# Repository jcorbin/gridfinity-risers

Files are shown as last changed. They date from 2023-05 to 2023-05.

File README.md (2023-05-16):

# Gridfinity Riser Modules

These are some riser modules useful for creating "cable basements" or otherwise
managing cable runs inside a gridfinity application.

Published STL models are published on [thangs](https://than.gs/m/853821)

Status:
- [x] working tunnel block for routing cables underneath a raised floor
- [x] tunnel towers can provide a sort of vertical conduit and/or support other
  modules; for example a AA battery charger stacked on top of a AA battery
  dispenser chute
- [x] tunnel sizes are reasonably flexible, clamping to available block space,
  and degrading to non-square rectangular tunnels when necessary
- [ ] consider switching the default tunnel size to 4u
- [ ] a baseplate variant of the tunnel block that is designed to sit well on a non-grid surface
  - maybe support edge pins to lock together multiple modules
  - maybe support cutting out voids for small devices embedded into the cable floor

## Tunnel Block

The primary module is a relatively solid/heavy block with tunnels cut along all 3 X/Y/Z axes for running cables.
The default tunnel size is 3u (21mm), which embeds well in a 4u-tall block.

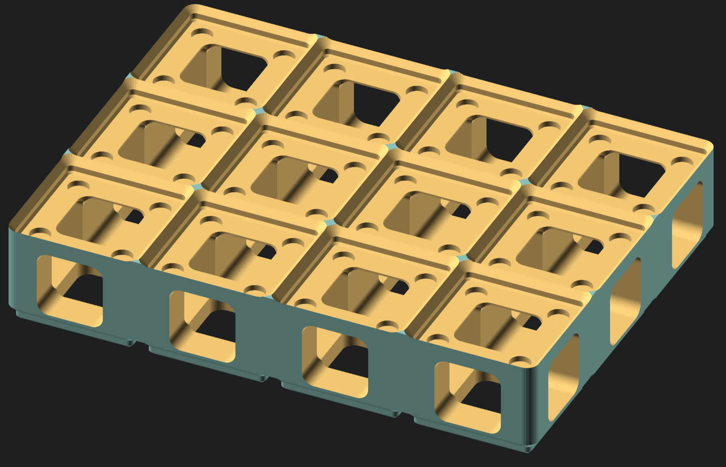
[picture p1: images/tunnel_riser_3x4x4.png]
Tunnel Block 3x4x4


## Tunnel Tower

When a tunnel block is scaled large enough in the Z axis, there will be
multiple layers of X/Y oriented tunnels, forming a tower.

With necessary margin, an `N` unit tall tunnel willl repeat every `N+1` units;
so the default 3u tunnel should repeat every 4u.

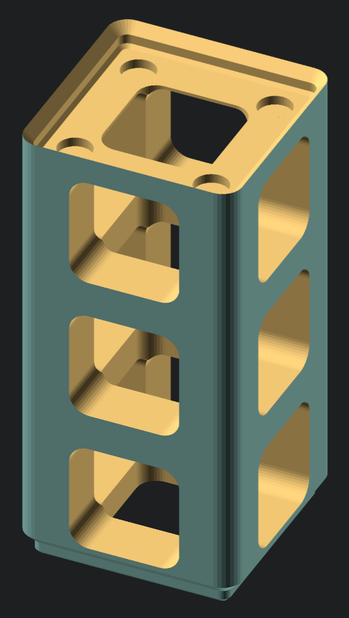
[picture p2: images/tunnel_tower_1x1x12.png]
Tunnel Tower 1x1x12


## Tunnel Baseplate

This is a variant of the tunnel block with a flat bottom meant to be used as a baseplate:
- features rabbit clips and sockets to allow multiple basepaltes to be locked together
- features pockets for rubber feet, default setup for 6x2mm feet (0.5mm deep pockets)

These are designed for a desktop grid module that you don't want to accidentally slide around.

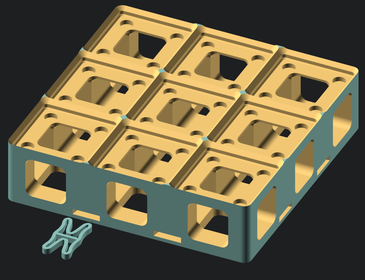
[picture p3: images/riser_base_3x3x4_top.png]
Tunnel Baseplate (top view)

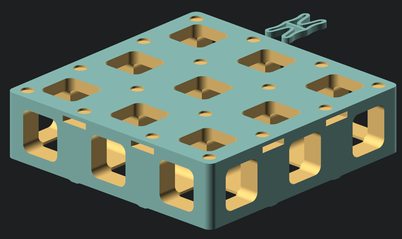
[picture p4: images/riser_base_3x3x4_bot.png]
Tunnel Baseplate (bottom view)


## Hexagonal Walled Cups

Inspired by a question in the Gridfinity discord, this is a recreation of a
gridfinity cup with most of the wall material cut out by a hexagon grid.
This model was created similarly to the tunnerl riser above,
using [vector76] gridfinity mmodules and [bosl2] to manage the hexagaon window cutouts.

A potential use here would be a stackable bin, whose contents would still be
visble thru the side when stacked:
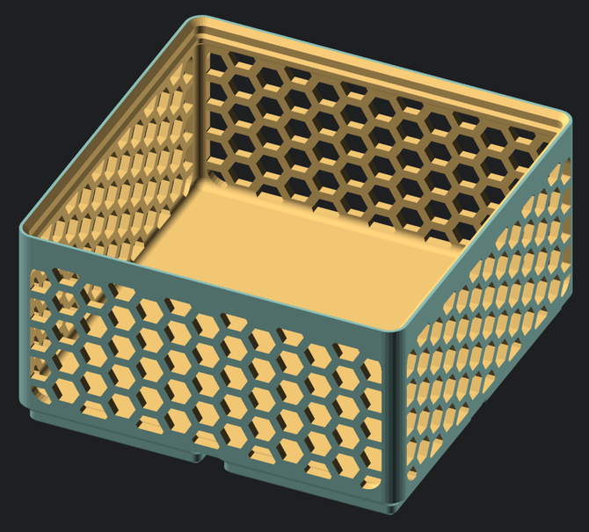
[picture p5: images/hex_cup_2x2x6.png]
Hex Cup 2x2x6


Or a non-stacking pen cup:
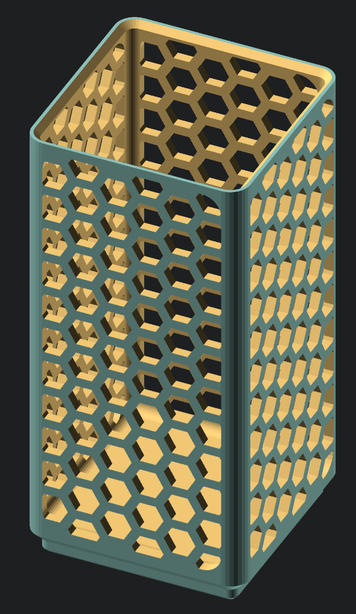
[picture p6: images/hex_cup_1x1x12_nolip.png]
Hex Cup 1x1x12 (no lip)


A similar cup can be seen in a picture uploaded by [ashleyi100 on thangs][ashleyi100]
which looks similar to this [non gridfinity box][hcomb_box] on printables.

## Raised Base

The initial design was a "legged table" based on [vector76] `frame_plain()` with extra height.

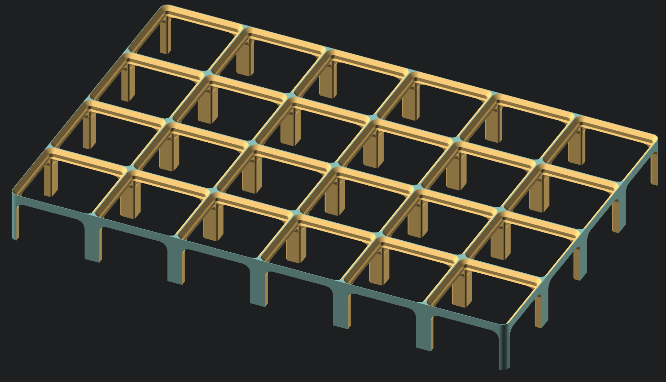
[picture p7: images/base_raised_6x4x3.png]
Raised Base "leg table" 6x4x3


This version didn't feel great in practice,
as the legs would chatter/skip over the external surface,
allowing cables to jump/dislocate too easily.

[ashleyi100]: https://thangs.com/designer/ashleyi100
[bosl2]: https://github.com/revarbat/BOSL2
[hcomb_box]: https://www.printables.com/model/250845-honeycomb-pattern-box-with-label
[vector76]: https://github.com/vector76/gridfinity_openscad

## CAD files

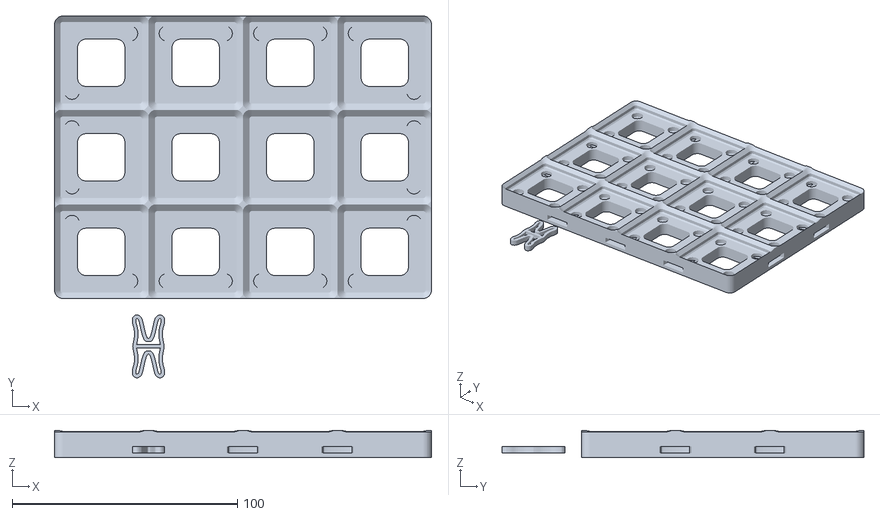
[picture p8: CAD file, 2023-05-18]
base_models/grid_base_4x3_with_clip.stl
167.5 x 160.8 x 12.0

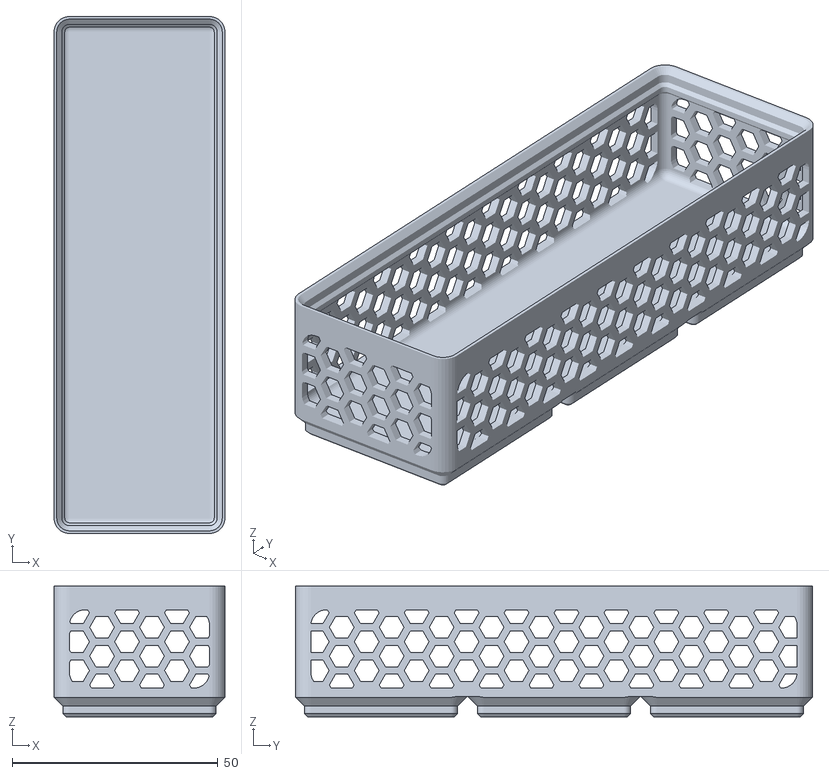
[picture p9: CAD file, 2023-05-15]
hex_cup_models/hex_cup_1x3x4.stl
41.5 x 125.5 x 31.8

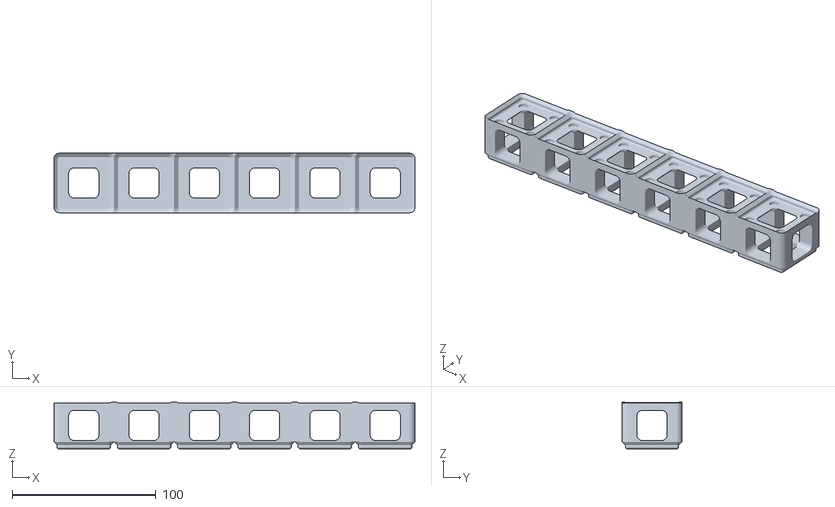
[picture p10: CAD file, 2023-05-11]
riser_models/tunnel_riser_6x1x4.stl
251.5 x 41.5 x 32.4

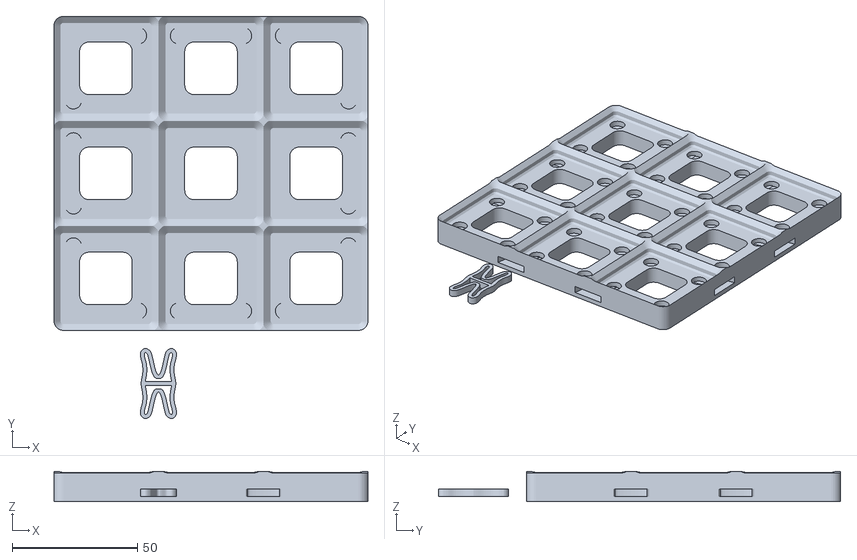
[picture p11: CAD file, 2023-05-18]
base_models/grid_base_3x3_with_clip.stl
125.5 x 160.8 x 12.0

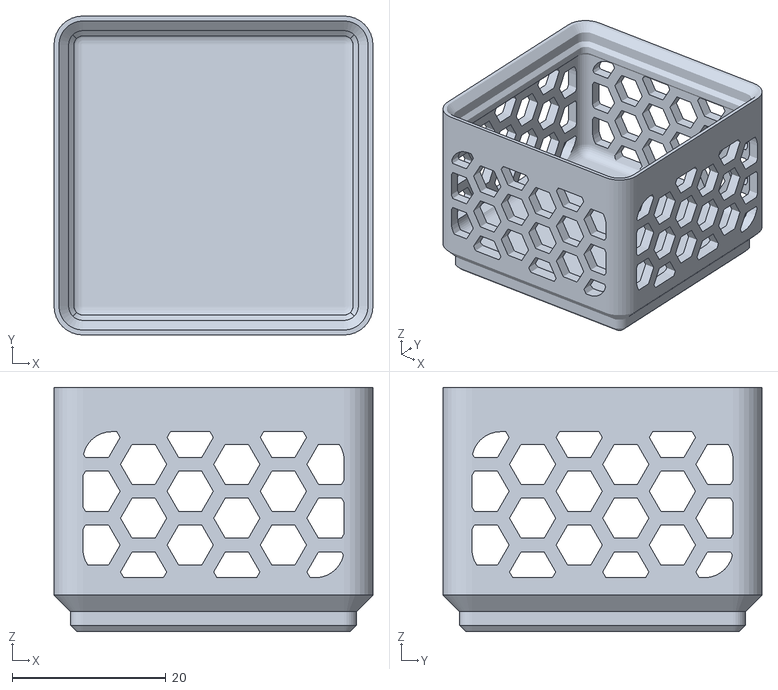
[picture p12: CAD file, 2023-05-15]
hex_cup_models/hex_cup_1x1x4_nolip.stl
41.5 x 41.5 x 31.8

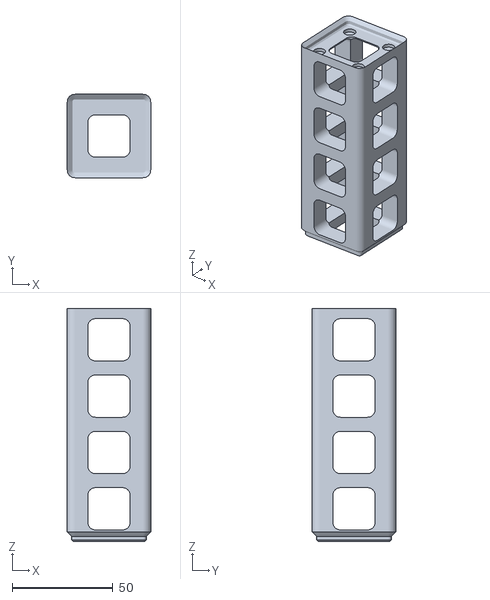
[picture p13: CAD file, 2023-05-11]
riser_models/tunnel_tower_1x1x16.stl
41.5 x 41.5 x 115.8

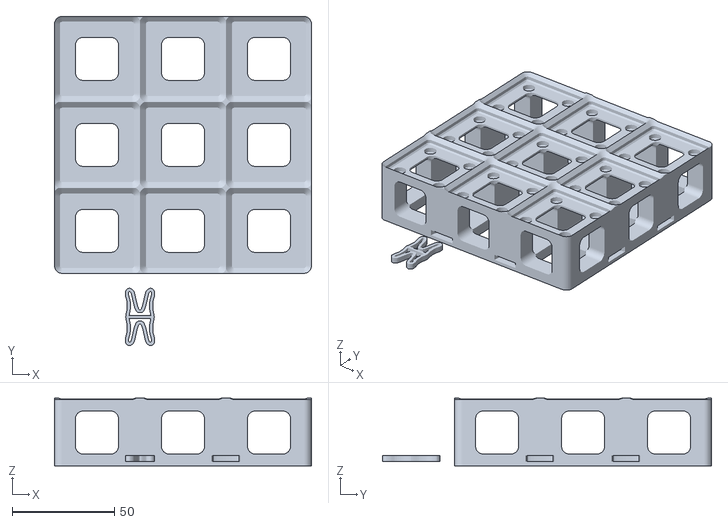
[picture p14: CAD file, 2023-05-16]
base_models/tunnel_base_3x3x4_with_clip.stl
125.5 x 160.8 x 33.0

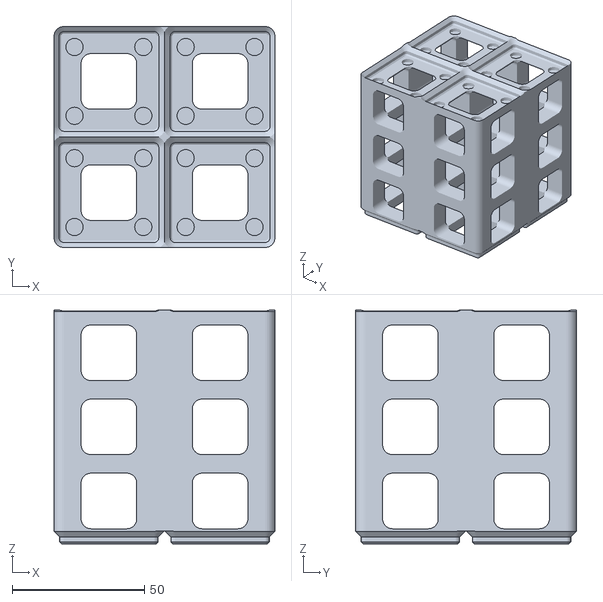
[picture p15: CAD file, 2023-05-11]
riser_models/tunnel_tower_2x2x12.stl
83.5 x 83.5 x 88.4

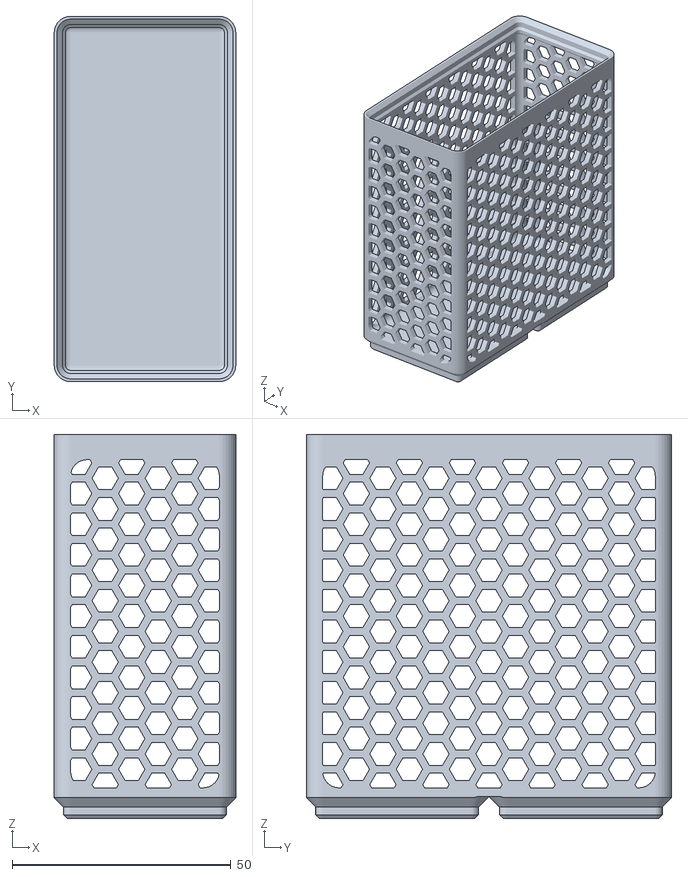
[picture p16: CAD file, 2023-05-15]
hex_cup_models/hex_cup_1x2x12.stl
41.5 x 83.5 x 87.8

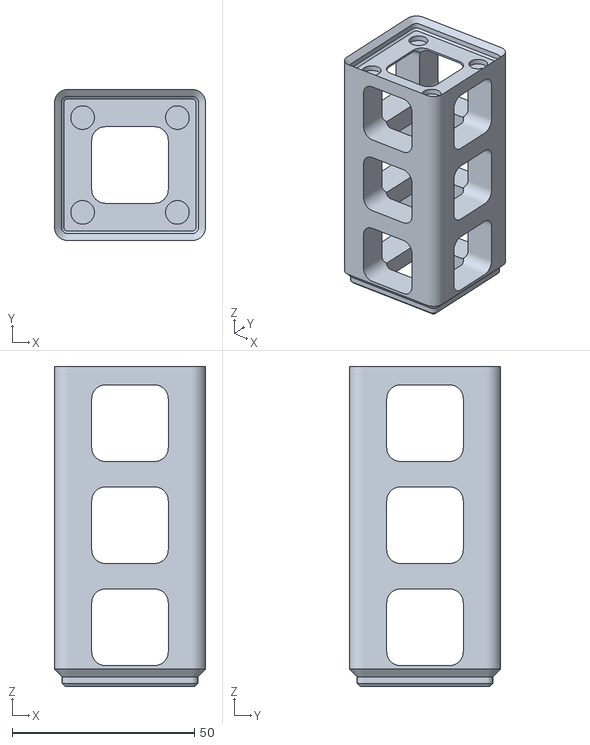
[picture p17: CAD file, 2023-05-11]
riser_models/tunnel_tower_1x1x12.stl
41.5 x 41.5 x 87.8

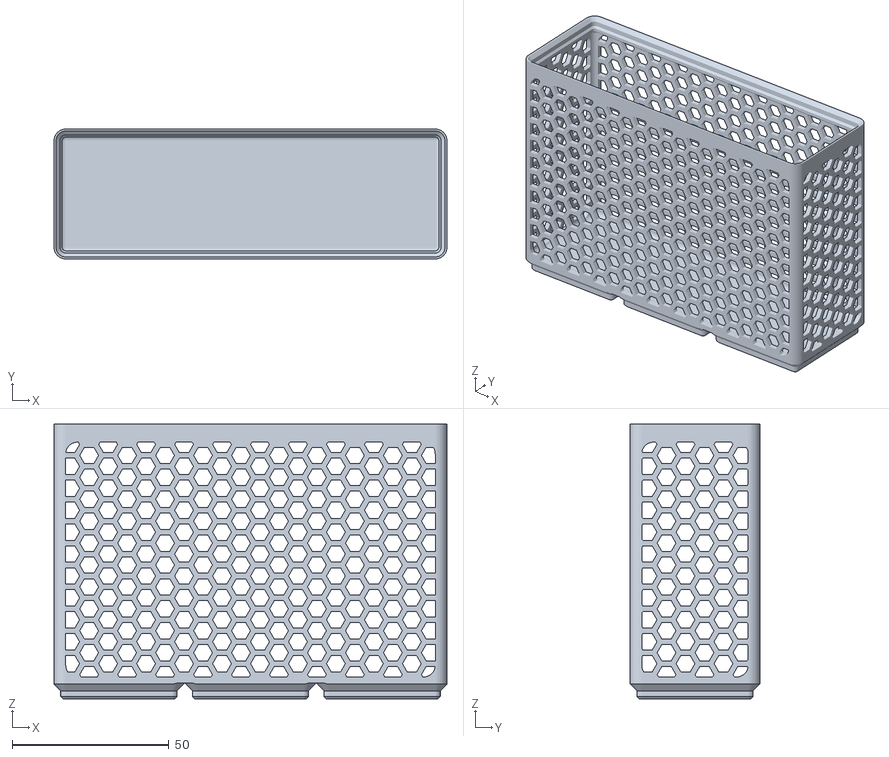
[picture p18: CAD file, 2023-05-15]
hex_cup_models/hex_cup_3x1x12.stl
125.5 x 41.5 x 87.8

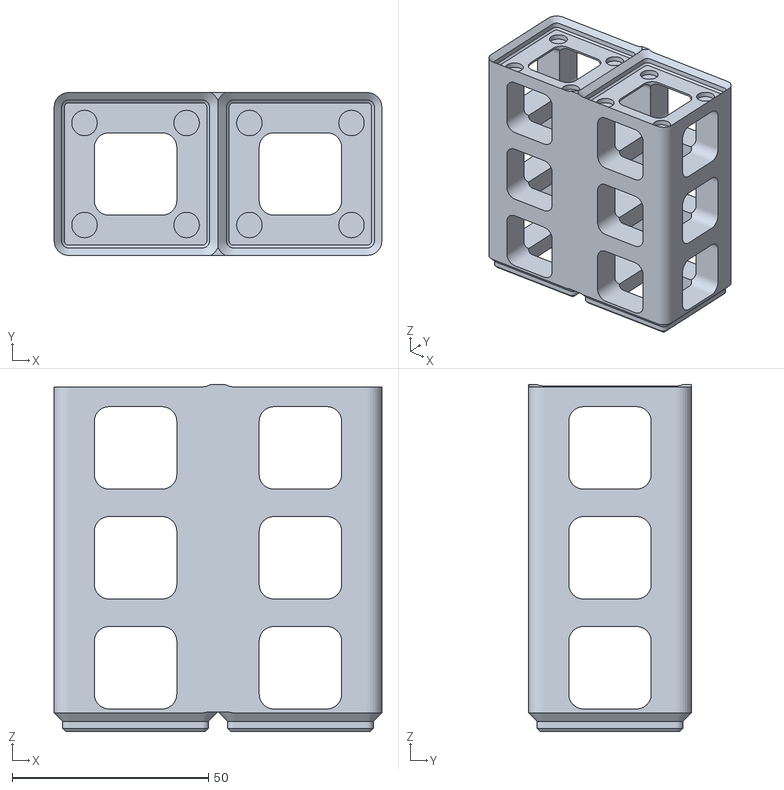
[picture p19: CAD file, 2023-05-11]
riser_models/tunnel_tower_2x1x12.stl
83.5 x 41.5 x 88.4

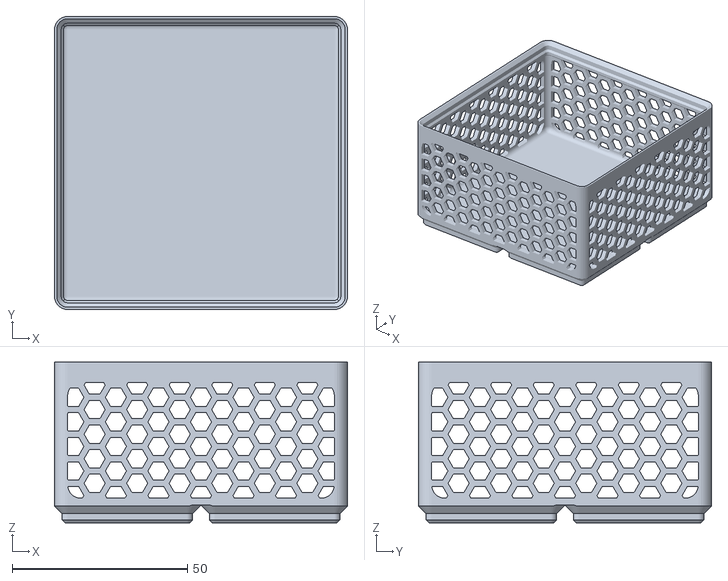
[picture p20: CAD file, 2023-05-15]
hex_cup_models/hex_cup_2x2x6.stl
83.5 x 83.5 x 45.8

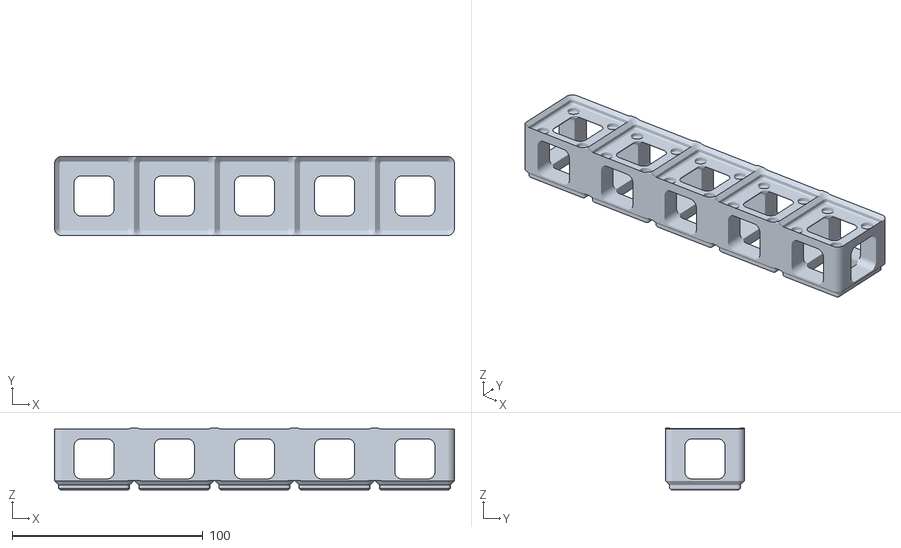
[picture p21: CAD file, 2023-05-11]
riser_models/tunnel_riser_5x1x4.stl
209.5 x 41.5 x 32.4

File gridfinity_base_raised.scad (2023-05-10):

include <vector76/gridfinity_modules.scad>
include <BOSL2/std.scad>

xsize = 6;
ysize = 4;
zsize = 3;

base_raised(xsize, ysize, raise=zsize);

module base_raised(num_x, num_y, raise=1) {
  difference() {
    corner_radius = 3.75;
    corner_position = gridfinity_pitch/2-corner_radius;

    height = gridfinity_zpitch * raise;
    door_width = 42 - 2*corner_radius;
    frame_height = 4.4;

    hull()
      cornercopy(corner_position, num_x, num_y)
      translate([0, 0, -height])
      cylinder(r=corner_radius, h=frame_height + height, $fn=44);

    translate([0, 0, -0.01])
      render()
      gridcopy(num_x, num_y)
      pad_oversize(margins=1);

    translate([0, 0, -(height+0.5)])
      cutout(num_x, num_y, h=height+1, margins=1);


    for(i=[0:num_x-1])
      translate([i * gridfinity_pitch, (num_y/2 - 0.5) * gridfinity_pitch, 0])
        cuboid([door_width, (num_y+0.5)*gridfinity_pitch, height+1], rounding=corner_radius, edges=TOP, anchor=TOP);

    for(i=[0:num_y-1])
      translate([(num_x/2 - 0.5) * gridfinity_pitch, i * gridfinity_pitch, 0])
        cuboid([(num_x+0.5)*gridfinity_pitch, door_width, height+1], rounding=corner_radius, edges=TOP, anchor=TOP);
  }
}

module cutout(num_x=1, num_y=1, h=1, margins=0) {
  pad_corner_position = gridfinity_pitch/2 - 4; // must be 17 to be compatible
  bevel1_top = 0.8;     // z of top of bottom-most bevel (bottom of bevel is at z=0)
  bevel2_bottom = 2.6;  // z of bottom of second bevel
  bevel2_top = 5;       // z of top of second bevel
  bonus_ht = 0.2;       // extra height (and radius) on second bevel

  // female parts are a bit oversize for a nicer fit
  radialgap = margins ? 0.25 : 0;  // oversize cylinders for a bit of clearance

  gridcopy(num_x, num_y)
  hull() cornercopy(pad_corner_position, 1, 1) {
    if (sharp_corners) {
      cylsq(d=1.6+2*radialgap, h=1);
    }
    else {
      cylinder(d=1.6+2*radialgap, h=h, $fn=24);
    }
  }
}

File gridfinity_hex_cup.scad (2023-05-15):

include <vector76/gridfinity_modules.scad>
use <vector76/gridfinity_cup_modules.scad>

include <BOSL2/std.scad>

// Block height (7mm unit).
height = 6;

// Grid X cell count (42mm aka 6u relative to height).
width = 2;

// Grid Y cell count (42mm aka 6u relative to height).
depth = 2;

// Hex cutout size in 7mm units.
// Make them bigger if planning pass larger objects (e.g. cables) through,
// or if the cup simply doesn't need to constrain smaller objects.
hex_size = 1;

// Whether to cut out hex cells whose center point is outside each wall cutout window.
// Can be useful for larger hex_size, but tends to create edge artifacts with small hex_size.
partial_hexes = false;

// How thick the walls should be.
// Controls both the extrusion depth from the outer cup perimiter to the interior,
// and the thickness of hexagonal cell walls.
// The default 1.8mm thickness turns out decently rigid,
// while dropping down to 0.95 can yield a much more flexible wall
wall_thickness = 1.8;

// Whether the cup should have magnet pockets.
magnets = true;

// Whether the cup should have magnet holes.
screws = false;

// What kind of lid the cup top should have:
// - "normal" and "reduced" allow for stacking
// - "none" can be used if you want more hexes and no stackability
lip_style = "normal";

hex_cup(
  width, depth, height,
  hex_size = hex_size,
  partial_hexes = partial_hexes,
  lip_style = lip_style,
  wall_thickness = wall_thickness,
  magnet_diameter = magnets ? 6.5 : 0,
  screw_depth = screws ? 6 : 0
);

module hex_cup(
  num_x, num_y, num_z,

  hex_size=1,
  partial_hexes = false,

  magnet_diameter=6.5,
  screw_depth=6,
  hole_overhang_remedy=false,

  floor_thickness=1.2,
  wall_thickness=1.8,
  efficient_floor=false,
  lip_style="normal",
  box_corner_attachments_only=false

) {

  hex_pitch = hex_size * gridfinity_zpitch;

  hex_wall = wall_thickness * 2;
  hex_extra = partial_hexes ? hex_pitch : 0;

  corner_radius = 3.75;
  eps = 0.01;

  x_outer_size = num_x * gridfinity_pitch - gridfinity_clearance;
  y_outer_size = num_y * gridfinity_pitch - gridfinity_clearance;
  z_outer_size = num_z * gridfinity_zpitch;

  floor_lift = 2;
  lip_height = lip_style == "none" ? 0 : lip_style == "reduced" ? 3 : 4;

  x_inner_size = x_outer_size - corner_radius * 2;
  y_inner_size = y_outer_size - corner_radius * 2;
  z_inner_size = z_outer_size - 5 - lip_height; // 5 for base
  z_inner_lift = floor_lift + (z_outer_size - z_inner_size)/2 - lip_height;

  difference() {

    center_vector76(num_x, num_y, num_z)
      grid_block(
        num_x, num_y, num_z,
        magnet_diameter=magnet_diameter,
        screw_depth=screw_depth,
        hole_overhang_remedy=hole_overhang_remedy,
        box_corner_attachments_only=box_corner_attachments_only
      );

    center_vector76(num_x, num_y, num_z)
      basic_cavity(
        num_x, num_y, num_z,
        fingerslide=false,
        magnet_diameter=magnet_diameter,
        screw_depth=screw_depth,
        floor_thickness=floor_thickness,
        wall_thickness=wall_thickness,
        efficient_floor=efficient_floor,
        lip_style=lip_style
      );

    // X axis aligned hex cutouts
    up(z_inner_lift) intersection() {
      cuboid(
        [x_outer_size+2, y_inner_size, z_inner_size],
        rounding=corner_radius,
        edges="X",
        $fn=32
      );

      left(x_outer_size/2+1)
      xrot(90)
      yrot(90)
      zrot(90)
        grid_copies(
          spacing=hex_pitch,
          stagger=true,
          inside=square(size=[z_inner_size + hex_extra, y_inner_size + hex_extra], center=true)
        )
          zrot(180/6)
          cylinder(h=x_outer_size+2, d=(hex_pitch - hex_wall/2)/cos(180/6) + eps, $fn=6);
    }

    // Y axis aligned hex cutouts
    up(z_inner_lift) intersection() {
      cuboid(
        [x_inner_size, y_outer_size+2, z_inner_size],
        rounding=corner_radius,
        edges="Y",
        $fn=32
      );

      back(y_outer_size/2+1)
      xrot(90)
      zrot(90)
        grid_copies(
          spacing=hex_pitch,
          stagger=true,
          inside=square(size=[z_inner_size + hex_extra, x_inner_size + hex_extra], center=true)
        )
          zrot(180/6)
          cylinder(h=y_outer_size+2, d=(hex_pitch - hex_wall/2)/cos(180/6) + eps, $fn=6);
    }

  }

}

// Origin fixup for using vector76 modules with bosl2
module center_vector76(num_x, num_y, num_z) {
  translate([
    (0.5 - num_x/2) * gridfinity_pitch,
    (0.5 - num_y/2) * gridfinity_pitch,
    (-num_z/2) * gridfinity_zpitch
  ]) children();
}

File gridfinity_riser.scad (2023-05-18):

include <vector76/gridfinity_modules.scad>

include <BOSL2/std.scad>
include <BOSL2/joiners.scad>

// Block height (7mm unit).
height = 4;

// Grid X cell count (42mm aka 6u relative to height).
width = 4;

// Grid Y cell count (42mm aka 6u relative to height).
depth = 3;

// Nominal tunnel size (7mm unit), will be clamped to available block space; 4u tunnels start to make sense in a 5u tall block.
tunnel_size = 3;

// If you don't need magnet attachments, 4u tunnels can be viable in even a 3u or 4u tall riser.
magnets = true;

// Optionally generate a standalone baseplate; default is to generate a stackable module.
base = false;

// Optionally enable rabbit clip sockets in baseplate mode.
// These clips allow adjacent baseplates to be clipped together to form a larger strucure.
//
// NOTE: when generating clip sockets, a double rabbit clip object is generated alongside the baseplate;
// suggested workflow is to split the generated STL apart into objects in your slicer,
// then duplicate the clip as many times as desired.
//
// NOTE: suggested slicer settings for the clip (at least what worked for me):
//       2 wall loops, no top/bottom layers, 0% infill.
//       Basically the clips should generate as pure/only wall loops.
base_clips = true;
base_clip_length = 2 * 7;
base_clip_width = 2 * 7;
base_clip_depth = 3;
base_clip_snap = 0.75;
base_clip_thick = 1.6;
base_clip_compress = 0.2;

// Optionally carve pockets for rubber feet underneath the standalone baseplate.
// These default are for 6x2mm rubber feet, which seemd a nice rhyme with the magnet metrics.
// Unlink magnets however, these are only barely recessed to help them stay in place.
//
// NOTE: set base_feet_diameter to 0 to disable.
base_feet_every = 2;
base_feet_diameter = 6.5;
base_feet_depth = 0.5;

tunnel_block(width, depth, height, size=tunnel_size, magnet_diameter=magnets ? 6.5 : 0, base=base);

if (base && base_clips) {
  fwd(21+base_clip_length*1.5) right(21) up(2)
  rabbit_clip(
    type="double",
    length=base_clip_length,
    width=base_clip_width,
    snap=base_clip_snap,
    thickness=base_clip_thick,
    depth=base_clip_depth,
    compression=base_clip_compress
  );
}

module tunnel_block(num_x, num_y, num_z, size=3, magnet_diameter=6.5, base=false, center=false) {
  height = num_z * gridfinity_zpitch;

  corner_radius = 3.75;
  eps = 0.1;

  // frame metrics adapted from frame_plain() but with corner meticis reconciled with grid_block()
  frame_height = (base ? num_z * gridfinity_zpitch : 0) + 5;
  frame_lift = base ? 0 : height - 0.6;
  frame_outer_size = gridfinity_pitch - gridfinity_clearance;  // typically 41.5
  frame_corner_position = frame_outer_size/2 - corner_radius;
  total_height = frame_lift + frame_height;

  magnet_position = min(gridfinity_pitch/2-8, gridfinity_pitch/2-4-magnet_diameter/2);
  magnet_thickness = 2.4;
  magnet_margin = magnet_diameter > 0 ? (gridfinity_pitch/2 - magnet_position + magnet_diameter/4) : 0;

  feet_position = min(gridfinity_pitch/2-8, gridfinity_pitch/2-4-base_feet_diameter/2);

  xy_tunnel_width = min(size, floor(gridfinity_pitch / gridfinity_zpitch));
  z_tunnel_width = min(size, floor((gridfinity_pitch - 2*magnet_margin) / gridfinity_zpitch));
  tunnel_height = min(size,
    // tunnel size bigger than 3u starts to slightly undercut magnet holes, needs more headroom
    magnet_diameter > 0 && size > 3 ? num_z-2 : num_z-1);

  translate( center ? [-(num_x-1)*gridfinity_pitch/2, -(num_y-1)*gridfinity_pitch/2, 0] : [0, 0, 0] )
  difference() {

    union() {
      // use a grid block body if not generating a standalone baseplate
      if (!base) {
        grid_block(num_x, num_y, num_z, screw_depth=0);
      }

      // top frame body
      translate([0, 0, frame_lift])
      hull()
        cornercopy(frame_corner_position, num_x, num_y)
        cylinder(r=corner_radius, h=frame_height, $fn=32);
    }

    // top frame cell cutouts
    translate([0, 0, base ? num_z * gridfinity_zpitch : frame_lift])
      render()
      gridcopy(num_x, num_y)
      pad_oversize(margins=1);

    // top magnet holes
    if (magnet_diameter > 0) {
      gridcopy(num_x, num_y) {
        cornercopy(magnet_position) {
          translate([0, 0, height-magnet_thickness])
          cylinder(d=magnet_diameter, h=magnet_thickness+eps, $fn=48);
        }
      }
    }

    if (base) {

      // interconnect clip sockets
      if (base_clips) {
        copy_grid_perim(num_x, num_y)
          up(2 + 3/2) rabbit_clip(
            type="socket",
            length=base_clip_length,
            width=base_clip_width,
            snap=base_clip_snap,
            thickness=base_clip_thick,
            depth=base_clip_depth,
            compression=base_clip_compress,
            orient=FRONT);
      }

      // feet pockets
      if (base_feet_diameter > 0) {
        copy_grid_feet(num_x, num_y, every=base_feet_every)
          cylinder(d=base_feet_diameter, h=2*base_feet_depth+eps, $fn=48);
      }

    }

    tunnels(
      num_x, num_y, num_z,
      x_width = xy_tunnel_width,
      y_width = xy_tunnel_width,
      z_width = z_tunnel_width,
      height = tunnel_height,
      margin = 2.25,
      total_height=total_height);
  }
}

module copy_grid_feet(num_x, num_y, every = 3) {
  every2 = is_list(every) ? every : [every, every];
  every_x = num_x % every2[0] == 1 && every2[0] > 1 ? every2[0] - 1 : every2[0];
  every_y = num_y % every2[1] == 1 && every2[1] > 1 ? every2[1] - 1 : every2[1];
  for (xi = [0 : every_x : num_x+1])
  for (yi = [0 : every_y : num_y+1])
  {
    translate([
      gridfinity_pitch * (xi - 0.5) + nudge(xi, gridfinity_pitch/6, num_x),
      gridfinity_pitch * (yi - 0.5) + nudge(yi, gridfinity_pitch/6, num_y),
      0
    ]) children();
  }
}

function nudge(i, by, last) = i == 0 ? by : i == last ? -by : 0;

module copy_grid_perim(num_x, num_y) {
  for (i = [1:num_y-1])
    translate([-0.5 * gridfinity_pitch, (i - 0.5) * gridfinity_pitch, 0])
    rotate([0, 0, 90])
      children();
  for (i = [1:num_y-1])
    translate([(num_x - 0.5) * gridfinity_pitch, (i - 0.5) * gridfinity_pitch, 0])
    rotate([0, 0, -90])
      children();
  for (i = [1:num_x-1])
    translate([(i - 0.5) * gridfinity_pitch, -0.5 * gridfinity_pitch, 0])
    rotate([0, 0, 180])
      children();
  for (i = [1:num_x-1])
    translate([(i - 0.5) * gridfinity_pitch, (num_y - 0.5) * gridfinity_pitch, 0])
      children();
}

module tunnels(
  num_x, num_y, num_z,
  x_width=3, // 7mm unit ; bore width of X oriented tunnels
  y_width=3, // 7mm unit ; bore width of Y oriented tunnels
  z_width=3, // 7mm unit ; bore width of Z oriented tunnels
  height=3, // 7mm unit ; bore height of X and Y oriented tunnels
  margin=0, // mm ; Z lift for each layer of tunnels
  total_width=0, // mm ; override num_x bound
  total_depth=0, // mm ; override num_y bound
  total_height=0 // mm ; override num_z bound
) {
  x_width_mm = x_width * gridfinity_zpitch;
  y_width_mm = y_width * gridfinity_zpitch;
  z_width_mm = z_width * gridfinity_zpitch;
  height_mm = height * gridfinity_zpitch;

  total_x = total_width == 0 ? num_x * gridfinity_pitch : total_width;
  total_y = total_depth == 0 ? num_y * gridfinity_pitch : total_depth;
  total_z = total_height == 0 ? num_z * gridfinity_zpitch : total_height;

  every = ceil((height_mm + margin) / gridfinity_zpitch) * gridfinity_zpitch;
  lift = margin + every/2;

  if (height_mm > 0) {
    for (layer = [0 : every : total_z - margin - height_mm]) {
      // X tunnels
      gridcopy(1, num_y)
      translate([-gridfinity_pitch/2-1, 0, layer + lift])
      rotate([0, 90, 0])
        tunnel(height_mm, x_width_mm, total_x + 2);

      // Y tunnels
      gridcopy(num_x, 1)
      translate([0, gridfinity_pitch * (num_y - 0.5)+1, layer + lift])
      rotate([90, 0, 0])
        tunnel(y_width_mm, height_mm, total_y + 2);
    }
  }

  // Z tunnels
  gridcopy(num_x, num_y)
  translate([0, 0, -1])
    tunnel(z_width_mm, z_width_mm, total_z + 2);
}

module tunnel(xsize, ysize, h) {
  corner_radius = min(3.75, xsize/4, ysize/4);
  dx = xsize/2 - corner_radius;
  dy = ysize/2 - corner_radius;
  hull() {
    translate([-dx, -dy, 0])
      cylinder(r=corner_radius, h=h, $fn=48);
    translate([dx, -dy, 0])
      cylinder(r=corner_radius, h=h, $fn=48);
    translate([-dx, dy, 0])
      cylinder(r=corner_radius, h=h, $fn=48);
    translate([dx, dy, 0])
      cylinder(r=corner_radius, h=h, $fn=48);
  }
}

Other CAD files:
hex_cup_models/hex_cup_1x1x4.stl
hex_cup_models/hex_cup_2x2x4.stl
riser_models/tunnel_tower_2x1x18.stl
hex_cup_models/hex_cup_1x3x6.stl
gridfinity_tripod.scad
hex_cup_models/hex_cup_1x1x12.stl
hex_cup_models/hex_cup_1x1x12_nolip.stl
hex_cup_models/hex_cup_1x1x6.stl
hex_cup_models/hex_cup_1x1x6_nolip.stl
hex_cup_models/hex_cup_1x2x4.stl
hex_cup_models/hex_cup_1x2x6.stl
hex_cup_models/hex_cup_1x3x12.stl
hex_cup_models/hex_cup_2x1x12.stl
hex_cup_models/hex_cup_2x1x4.stl
hex_cup_models/hex_cup_2x1x6.stl
hex_cup_models/hex_cup_2x2x12.stl
hex_cup_models/hex_cup_2x3x12.stl
hex_cup_models/hex_cup_2x3x4.stl
hex_cup_models/hex_cup_2x3x6.stl
hex_cup_models/hex_cup_3x1x4.stl
hex_cup_models/hex_cup_3x1x6.stl
hex_cup_models/hex_cup_3x2x12.stl
hex_cup_models/hex_cup_3x2x4.stl
hex_cup_models/hex_cup_3x2x6.stl
hex_cup_models/hex_cup_3x3x4.stl
hex_cup_models/hex_cup_3x3x6.stl
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

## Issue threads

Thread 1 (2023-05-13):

Port to kennetek / merge with nascent rerebuild project

jcorbin, 2023-05-13:
So I originally went with vector76 after a brief look at kennetek's code, because the module decomposition in vector76's code made more sense to my brain:
- with vector76 the modules are things like `grid_block()` and `frame_plain()` with utilities like `cornercopy()`
- but kennetek module are super generic things like `gridfinityInit()` and `gridfinityBase()` which gave me "enterprise factory bean" vibes, so I stopped reading the kennetek code beyond the particular toplevel part files
- cavaet: I'm still new to the openscad language, this riser project is my first substantial thing that I've done in it, so I'm only going on my general sense of code quality here

However the kennetek models seem to be more feature complete / polished, and perhaps more importantly, there appears to be more developer engagement/velocity around the kennetek codebase (including interest in merging in a remake of these risers).

Plus there seems to be some interest in rerebuilding the kennetek codebase, which might address my original concerns about code (re)factoring / module (de)composition:
- https://github.com/orgs/scadgrid/projects/3/views/1?pane=issue&itemId=28114445
- https://github.com/DJDDDM/gridfinity-rebuilt-openscad/tree/main/playground/gridfinity%20rerebuild/code

Plan:
- [ ] just try out a riser remake using the current mainline kennetek code
- [ ] do it again using nascent rerebuild code linked above
- [ ] depending on how well those go, and where we're at with any shared (re)organization building, PR the newly remade risers

jcorbin, 2023-05-13:
Tangentially related to the rerebuild code quality discussion:
- would using the [BOSL2](https://github.com/revarbat/BOSL2) library simplify things much?
- the only other openscad code I've written so far has been for the honeycomb storage wall, and the model I started from there used bosl2 (sorry not on github, but here are some of the uploaded models):
  - https://www.printables.com/model/473815-weller-wlc100-honeycomb-storage-wall-mount/files
  - https://www.printables.com/model/469713-honeycomb-storage-wall-hook-mount/files
- in the case of vector76's code which I'm more familiar with so far, at least good portions of it would simplify away using bosl2's `cuboid()` module, rather than defining similar cylider-hulls all over the place

However, there is always operational cost do adding a dependency, especially here in openscad land where that probably looks like "use a git submodule" since scad seems closer to C/C++ insofar as it has no internal version/dependency management system beyond `include`.

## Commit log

2023-05-10 Add original base_raised concept
    This was an initial "legged table" approach that was abandoned once the
    riser module notion was gained traction.
    [gridfinity_base_raised.scad]
2023-05-10 Add tunnel riser module
    Decrustified out of my hacked working copy of vector76:
    - reconciled mionor discrepency between frame corner and block body
    corner positions that was causing a minor lip artifact
    [gridfinity_riser.scad]
2023-05-10 Add a README with render samples
2023-05-11 Add riser tunnel z-layering
    [gridfinity_riser.scad]
2023-05-11 Generate riser models
    - tunnel plates up to 6x5
    - towers up to 2x2x20
    [tunnel_riser_1x1x4.stl, tunnel_riser_1x2x4.stl, tunnel_riser_1x3x4.stl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]
2023-05-13 Add top magnet hole branch
    [gridfinity_riser.scad]
2023-05-13 Support non-square tunnels
    Just in the inner tunnel() module for now.
    [gridfinity_riser.scad]
2023-05-13 Pushdown tunnel size unit conversion
    Also add separte variables to drive rectangular tunnels.
    [gridfinity_riser.scad]
2023-05-13 Clamp given tunnel size
    To avaiilable space, generating non-square tunnels if necessary.
    [gridfinity_riser.scad]
2023-05-13 Pivot toplevel tunnel_size variable
    [gridfinity_riser.scad]
2023-05-13 Expose magnet_diameter parameter
    [gridfinity_riser.scad]
2023-05-13 Make tunnel_height clamp more conservative
    Clamp in terms of logical units and whether magnets are used at all.
    [gridfinity_riser.scad]
2023-05-13 Improve toplevel riser variables
    Add doc comments and rename x/y/z logically.
    [gridfinity_riser.scad]
2023-05-13 Factor out tunnel() module
    [gridfinity_riser.scad]
2023-05-14 Cleanup tunnel_block magnet variables
    [gridfinity_riser.scad]
2023-05-14 Add gridfinity hex_cup model
    [gridfinity_hex_cup.scad]
2023-05-14 Increase hex_cup default thickness
    [gridfinity_hex_cup.scad]
2023-05-14 Add rendered hex cup models
    [hex_cup_1x1x12.stl, hex_cup_1x1x12_nolip.stl, hex_cup_1x1x4.stl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]
2023-05-15 Fix several x-vs-y bugs in hex cup
    [gridfinity_hex_cup.scad, hex_cup_1x1x12.stl, hex_cup_1x1x12_nolip.stl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]
2023-05-16 Add x/y tunnel height guard
    Diables x/y tunnels when height is insufficient
    [gridfinity_riser.scad]
2023-05-16 Add standalone tunnel baseplate mode
    Features rabbit clip interconnects and rubber feet pockets.
    [gridfinity_riser.scad]
2023-05-16 Add some riser baseplate models
    [tunnel_base_3x3x4_with_clip.stl]
2023-05-18 Add centering to tunnel_block
    [gridfinity_riser.scad]
2023-05-18 Add prototype tripod plate
    [gridfinity_tripod.scad]
2023-05-18 Rework tripod mount to use a feature tunnel block
    [gridfinity_tripod.scad]
2023-05-18 Dedupe redundant riser model generation
    [tunnel_riser_1x2x4.stl, tunnel_riser_1x3x4.stl, tunnel_riser_1x4x4.stl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]
2023-05-18 Add some 1u grid base models
    [grid_base_3x3_with_clip.stl, grid_base_4x3_with_clip.stl]
